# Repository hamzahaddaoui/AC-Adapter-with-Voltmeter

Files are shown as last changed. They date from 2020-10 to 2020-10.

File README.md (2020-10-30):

# AC-Adapter-with-Voltmeter

The project's purpose was to build an AC adapter using linear components (7805 and LM317), since it is made for hobbystic purposes (low currents are drawn). 
One source of voltage is fixed at 5V and the other can be adjusted (1.2v to 14v) using a potentiometer. 

The second part of the project was building a voltmeter, sensing it using the microcontroller internal ADC (16bit) and showing it on the 7-segments display. 
The accuracy of the voltage measurement is about 0.1V.

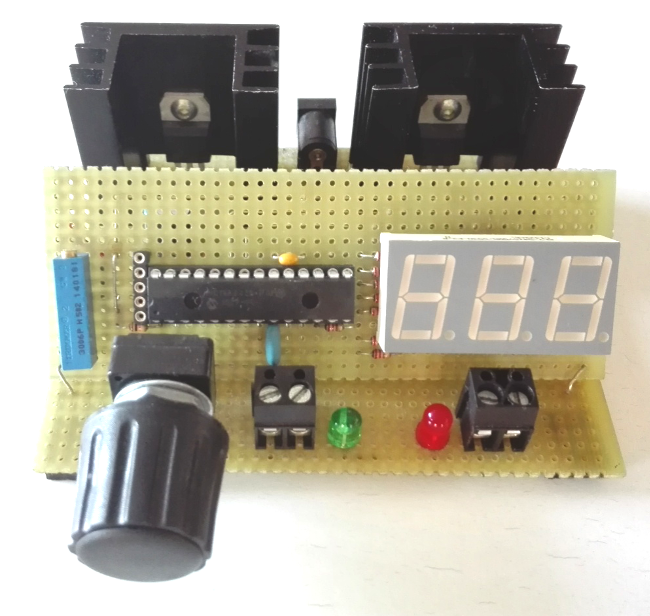
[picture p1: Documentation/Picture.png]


### Electronics schematic

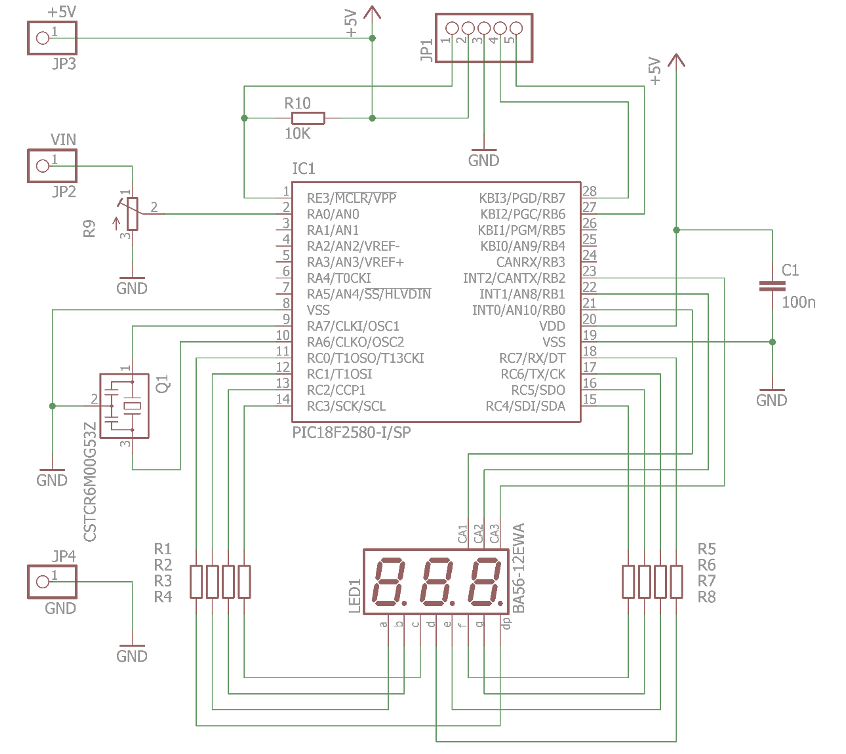
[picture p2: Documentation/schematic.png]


### PCB schematic

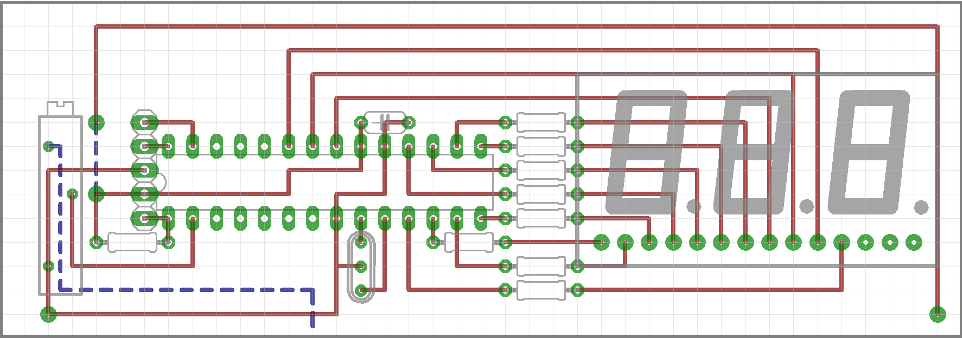
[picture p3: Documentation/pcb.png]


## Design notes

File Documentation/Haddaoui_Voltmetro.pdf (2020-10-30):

# VOLTMETRO A 3 DIGIT

Hamza Haddaoui | 4ECn 2015/16

Il voltmetro è uno strumento (https://it.wikipedia.org/wiki/Strumento_di_misura) per la misura della differenza di potenziale (https://it.wikipedia.org/wiki/Differenza_di_potenziale) elettrico tra due punti di un circuito, (https://it.wikipedia.org/wiki/Circuito_elettrico) la cui unità di misura è il volt (https://it.wikipedia.org/wiki/Volt) con simbolo V.
Come per altri strumenti, i parametri fondamentali di un voltmetro sono:
- la portata
- la sensibilità
Il voltmetro da noi realizzato misura la tensione tra il riferimento (GND) e la tensione variabile in uscita dall'alimentatore.
L'alimentatore fornisce una tensione compresa tra 1,2V e 16V, che viene misurata dal voltmetro con una precisione di 0,1V.
1. Microcontrollore Microchip PIC18F2420
2. Zoccolo a 5 poli per la programmazione
3. Trimmer multigiro 10K
4. Display a 3 cifre (catodo comune)

2

3

4

1

## Funzionamento

Il funzionamento del voltmetro può essere descritto in tre fasi, che vengono eseguite a intervalli ben precisi, dettati dal timer interno, che sono:
- Lettura della tensione (Input);
- Elaborazione dei dati raccolti;
- Visualizzazione della tensione sul display (Output).

### Lettura della tensione

Il primo step riguarda l'acquisizione della tensione, effettuata mediante la lettura analogica della tensione dal micro.
Il pin RA0 del PIC, "legge" la tensione sul trimmer, che non è altro che la tensione variabile erogata dall'alimentatore, partizionata.
Si adotta questa tecnica poiché è necessario
regolare la tensione in ingresso al micro, cioè
“rimappare” la tensione tra 1,2V e 16V in una tensione tra 0 e 5v (in modo proporzionale). Nella fase finale di collaudo è quindi necessario tarare il trimmer per regolare la tensione in ingresso al PIC.

### Elaborazione dati

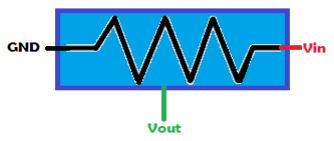
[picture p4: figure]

Successivamente, è necessario elaborare il dato letto sul pin RA0. La conversione A/D utilizzata è a 8bit, cioè ha una risoluzione di circa 60mV.
Una volta letto il byte, bisogna convertirlo in una tensione secondo la proporzione:

byte ∶ tensione = 2

8
∶ 16V

tensione =

byte ∗ 16V

unsigned char var;

var += readADCH0()); | //lettura AN0 e sommatoria

i++;

if (i==40){ | //media su 40 misure

i=0;

tensione=var/40;

var=0;

dividicifre();

}

Un altro appunto molto importante da tenere a mente, è che il regolatore di tensione “LM317” fornisce una tensione in uscita a partire da 1,2V, quindi tensioni più basse sono indice di malfunzionamento del software (oppure, la calibrazione con il trimmer non è stata effettuata correttamente).

La fase successiva consiste nel suddividere la tensione in singole cifre, quali decine, unità e decimi. Fatto ciò, bisogna codificare ogni singola cifra con un codice binario, relativo ai segmenti da accendere:

| a | b | c | d | e | f | g
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
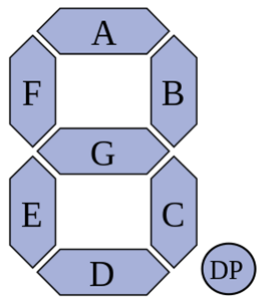
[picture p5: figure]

Ad esempio, per la cifra “7” i segmenti da accendere saranno “a”, “b” e “c”.

### Visualizzazione tensione

Per visualizzare la tensione sul display, è necessario a livello hardware collegare i vari segmenti ai pin relativi del PIC, tramite una resistenza per limitare la corrente sui vari LED.

Nel display utilizzato i segmenti della stessa
lettera sono collegati tra di loro (Il segmento
“a” della prima cifra è collegato con il
segmento “a” della seconda e terza cifra), cosa che risulta molto comoda dal momento che con 7 fili (+ un catodo per ogni cifra) possiamo comandare 3 cifre.
La configurazione del display utilizzato (ELT-541SYGWA) infatti è a catodo comune, cioè

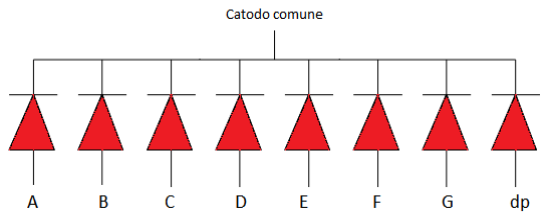
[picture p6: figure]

tutti i segmenti di una cifra, sono collegati da un unico pin sul catodo.

Per visualizzare un numero, basta mandare al display il codice relativo alla prima cifra, attivare il catodo (quindi portarlo a GND), disattivarlo e ripetere la procedura per le altre due cifre.
La velocità con cui viene effettuata questa operazione è così veloce che il nostro occhio non si accorge del continuo accendersi e spegnersi delle cifre.

## Schema elettrico

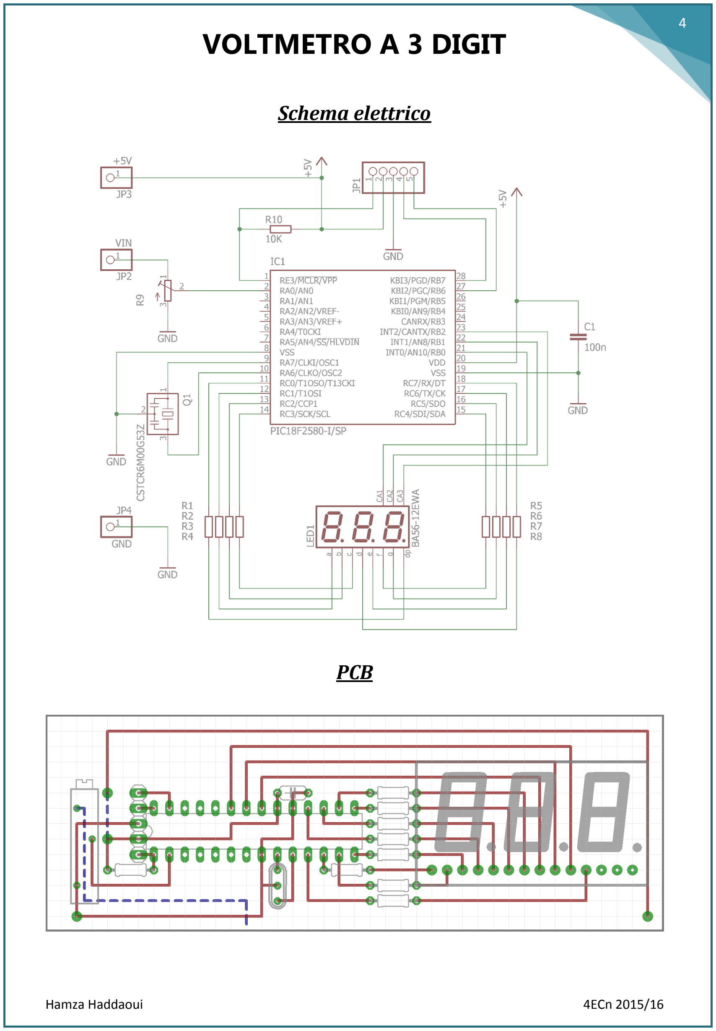
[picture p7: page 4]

## PCB

## Note di montaggio

- Saldare con attenzione lo zoccolo a 28 pin del PIC, facendo in modo che sia perfettamente a contatto con la basetta
- Saldare il connettore da 14 pin per il display, e quello da 5 pin per la programmazione
- Saldare le varie resistenze, il condensatore ed il trimmer
- Il risonatore ceramico non è indispensabile, poiché nel PIC è già integrato un oscillatore

## Collaudo e calibrazione

Il primo collaudo effettuato è stato per verificare che tutti i segmenti del display fossero effettivamente funzionanti.

Successivamente una volta completata la realizzazione della scheda, si passa a un collaudo visivo, tenendo sottomano lo schema PCB del circuito, per individuare varie incongruenze.

La fase successiva riguarda la programmazione del PIC, effettuata con il software MPLAB IDE.
Tramite la strip a 5 poli, si collega il MiniPic al voltmetro, avendo cura di togliere i ponticelli per “scollegare” il PIC18F4580 e programmare appunto il PIC18F2420 presente sul voltmetro.

Se la programmazione va a buon fine, sul display si dovrà visualizzare la scritta “ccc”: a questo punto si passa alla fase di calibrazione.

Nella fase di calibrazione bisogna alimentare il voltmetro (5V, GND) sui relativi pin, e portare il pin Vout su una tensione a piacere (preferibilmente sotto i 5V). A questo punto è necessario regolare il trimmer per leggere sul display la tensione applicata sul pin.

## Problemi riscontrati

Nel realizzare il voltmetro non ho avuto problemi. Dopo aver programmato il microcontrollore, ho notato che i segmenti del display relativi alla “g” non funzionavano. Inizialmente pensavo che fosse un problema del display, invece poi facendo varie prove ho scoperto che era il pin del microcontrollore collegato al pin “g” del display che non funzionava, perciò ho sostituito il microcontrollore.

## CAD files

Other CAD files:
src/output/progetto.obj

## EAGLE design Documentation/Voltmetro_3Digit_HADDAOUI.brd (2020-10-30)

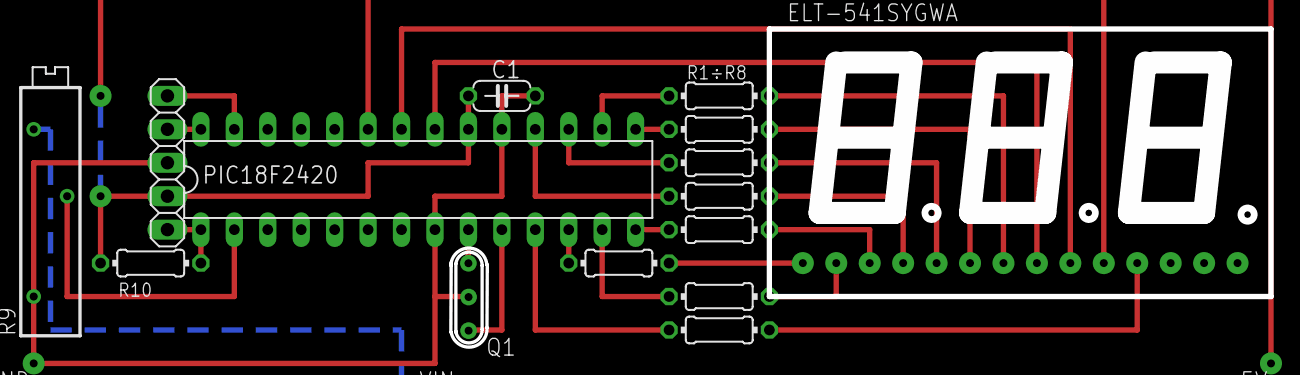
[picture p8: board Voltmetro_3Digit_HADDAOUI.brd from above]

Board: 2 copper layers, 13 parts (0 on the bottom side), 14 nets.

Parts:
C1: 100n; C050-024X044
JP1: 1X05
PIC18F2420: DIL28-3
R1÷R8, R2, R3, R4, R5, R6, R7, R8: 220; 0204/7
R9: 10K; RTRIM3006P
R10: 10K; 0204/7

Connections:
S$2: PIC18F2420.18, R3.1
S$3: PIC18F2420.17, R7.1
S$4: PIC18F2420.15, R2.1
S$5: PIC18F2420.16, R1÷R8.1
S$15: C1.1, R10.1
S$16: C1.2, JP1.3, PIC18F2420.19, R9.1
S$19: PIC18F2420.11, R8.1
S$22: PIC18F2420.12, R5.1
S$23: PIC18F2420.13, R6.1
S$24: PIC18F2420.14, R4.1
S$30: JP1.4, PIC18F2420.28
S$31: JP1.5, PIC18F2420.27
S$33: JP1.1, PIC18F2420.1, R10.2
S$34: PIC18F2420.2, R9.2

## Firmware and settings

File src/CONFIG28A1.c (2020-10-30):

/*
#asm // like this...
movlb (_var) > > 8
rlcf (_var)&0ffh,f
#endasm
asm(“movlb (_var)> >8”);
asm(“rlcf (_var)&0ffh,f”);
void setCN1{	



void setCN1(unsigned char xx){
	extern unsigned char xy;
	xy=xx;
	#asm
		movff	_xy,WREG
		clrf	WREG
		clrf	INTCON
		clrf	_forx
		clrf	_xy
	#endasm
}
*/








// Modulo di configurazione per PIC18F2580
//=============================================================

#pragma	config IESO=OFF, FCMEN=OFF
	
//OSCINT (FREQ <4MHZ,8MHZ,16MHZ,32MHZ>)
//OSCINT_CKOUT	(il segnale di CLOCK è presente sul pin P10)
//OSCXT
//OSCHS
//OSCHSPLL


//defaul OSCINT, FREQ=4MHz RA6/RA7 digital 
#if defined OSCXT
	#pragma config OSC=XT
#elif defined OSCHS
	#pragma config OSC=HS
#elif defined OSCHSPLL
	#pragma config OSC=HSPLL
#elif defined OSCINT
	#pragma config OSC=IRCIO67
#elif defined OSCINTCKOUT
	#pragma config OSC=IRCIO7
#else
	#pragma config OSC=IRCIO67
#endif


#pragma	config BOREN=OFF, PWRT=ON
#pragma config WDT=OFF
#pragma config PBADEN=OFF
#pragma config DEBUG=ON, STVREN=ON, XINST=OFF, LVP=OFF

//=============================================================
//	dichiarazioni di utilità


unsigned char utilechar0,utilechar1,utilechar2,utilechar3;
unsigned int utileint0,utileint1,utileint2,utileint3;
unsigned char kh,kl,hh,hl;

#ifdef MPWM1
	unsigned char contaMPWM1;
#endif
#ifdef MPWM2
	unsigned char contaMPWM2;
#endif
#ifdef MPWM3
	unsigned char contaMPWM3;
#endif
#ifdef MPWM4
	unsigned char contaMPWM4;
#endif
#if defined MPWM1 || defined MPWM2 || defined MPWM3 || defined MPWM4
	unsigned char periodoMPWM;
#endif

//=============================================================

void configPIC(void)
{
	
	//configurazione di default, periferiche tutte disabilitate
	T0CON=0;				//TIMER0
	T1CON=0;				//TIMER1
	T2CON=0;				//TIMER2
	T3CON=0;				//TIMER3
	CCP1CON=0;				//CCP1 (PWM)
	SSPCON1=0;				//MSSP
	RCSTA=0;				//EUSART
	ADCON1=0x0F;ADCON0=0;	//ingressi tutti digitali
	HLVDCON=0;				//HLV
	CANCON=0b00100000;		//CAN
			
	//-------------------------
	OSCCON=0b01100000;		//default 4MHZ
	PLLEN=0;				//default PLL disable

	//--------------------------
	#if defined OSCINT || defined OSCINTCKOUT
		#if FREQMHZ == 8 
			OSCCON=0b01110000;	//8MHZ
		#elif FREQMHZ == 16
			PLLEN=1;			//4MHZ con PLLx4
		#elif FREQMHZ == 32
			OSCCON=0b01110000;	//8MHZ
			PLLEN=1;			//PLLx4
		#endif
	#endif	

	//------------------------------------------------------
	// registri speciali del micro utilizzati
	RXM0EIDH=0;RXM0EIDL=0;	//VPWM1
	RXM1EIDH=0;RXM1EIDL=0;	//VPWM1
	RXF1EIDH=0;RXF1EIDL=0;	//VPWM1
	RXF5EIDH=0;RXF5EIDL=0;	//VPWM1


	//------------------------------------------------------
	// variabili da inizializzare
	#ifdef MPWM1 
		contaMPWM1=0; 
	#endif
	#ifdef MPWM2 
		contaMPWM2=0; 
	#endif
	#ifdef MPWM3 
		contaMPWM3=0; 
	#endif
	#ifdef MPWM4 
		contaMPWM4=0; 
	#endif				

	//------------------------------------------------------
	//	PORTA (default tutti DIGITAL INPUT)
	
	TRISA=0xFF;
	LATA=0;
	ADCON1=0x0F;
	
	#if defined OSCINTCKOUT || defined OSCINT
		#if defined P9OUT
			TRISA7=0;
			#define P9	LATA7
		#else
			#define P9	RA7
		#endif
	#endif
	
	#if defined OSCINTCKOUT
		TRISA6=0;
		#undef P10
	#endif
	
	#if defined OSCINT
		#if defined P10OUT
			TRISA6=0;
			#define P10	LATA6
		#else
			#define P10	RA6
		#endif
	#endif

	#ifdef P7OUT
		TRISA5=0;
		#define P7	LATA5
	#else
		#define P7 	RA5
	#endif

	#ifndef P6COUNTER0CKI
		#ifdef P6OUT
			TRISA4=0;
			#define P6	LATA4
		#else
			#define P6 	RA4
		#endif
	#endif
	
	#ifdef P5OUT
		TRISA3=0;
		#define P5	LATA3
	#else
		#define P5 	RA3
	#endif
	
	#ifdef P4OUT
		TRISA2=0;
		#define P4	LATA2
	#else
		#define P4 	RA2
	#endif

	#ifdef P3OUT
		TRISA1=0;
		#define P3	LATA1
	#else
		#define P3	RA1
	#endif

	#ifdef P2OUT
		TRISA0=0;
		#define P2	LATA0
	#else
		#define P2	RA0
	#endif
		
	//------------------------portB

	TRISB=0xFF;
	LATB=0;
	
	#ifdef RPULLUP
		RBPU=0;
	#endif
		
	#if !defined intP21
		#ifdef P21OUT
			TRISB0=0;
			#define P21	LATB0
		#else
			#define P21 RB0
		#endif
	#else
		#define P21 RB0		
	#endif
	
	#if !defined intP22
		#ifdef P22OUT
			TRISB1=0;
			#define P22	LATB1
		#else
			#define P22 RB1
		#endif
	#else
		#define P22 RB1		
	#endif
	
	#ifdef P23OUT
		TRISB2=0;
		#define P23	LATB2
	#else
		#define P23 RB2
	#endif

		
	#ifdef P24OUT
		TRISB3=0;
		#define P24	LATB3
	#else
		#define P24 RB3
	#endif
	
	#ifdef P25OUT
		TRISB4=0;
		#define P25	LATB4
	#else
		#define P25 RB4
	#endif
	
	#ifdef P26OUT
		TRISB5=0;
		#define P26	LATB5
	#else
		#define P26 RB5
	#endif

	//-----------------------PORTC
	
	TRISC=0xFF;
	LATC=0;
	CCP1CON=0;
	SSPCON1=0;
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

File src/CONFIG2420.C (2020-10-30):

//configurazione 18F2420
#include <htc.h>

#pragma config OSC = INTIO7, PWRT = ON,BOREN = OFF,WDT = OFF,PBADEN = OFF
#pragma config MCLRE = ON,LVP = OFF,DEBUG = ON
#define interruptTIMER0(void) interrupt TIMER0(void)

#define BYTE1 LATC
#define P21 LATB0
#define P22 LATB1
#define P23 LATB2
unsigned int usec;
unsigned int restart;

void configPIC (void){
	LATC=0;
	TRISC=0;
	LATB=0;
	TRISB=0b11111000;
	OSCCON=0b01100000;	//4MHz
	ADCON0=1;
	ADCON1=0b00001110;
	ADCON2=0b00100100;
	//T0CON=0b01000100;	//:32 (cost. 62)
	TMR0=62;
	INTCON=0;
}

unsigned char readADCH0(void){
	unsigned char datoAD;

	ADCON0=0b00000011;
	while (GODONE)continue;
	ADIF=0;
	datoAD=ADRESH;
	return datoAD;
}

void restartTIMER0(void){

	TMR0=-(restart/32);
	TMR0IF=0;
}

void setTIMER0CKINT(usec){
	restart=usec;
	T0CON=0b01000100;	//:32
	TMR0IF=0;
	TMR0=usec/32;
}


void setAD(char nbit, char nch){
	ADCON0=0b00000001;			//AD on
	//if(nbit==8)ADCON2=0b00000010; 
	//else ADCON2=0b10000010;
	if(nbit==8)ADCON2=0b00100010; 
	else ADCON2=0b10100010;
		
	switch (nch){
		case 1:	ADCON1=0b00001110;break;
		case 2: ADCON1=0b00001101;break;
		case 3: ADCON1=0b00001100;break;
		case 4: ADCON1=0b00001011;break;
	}
}
	
void enintGLOB(){
	GIE=1;
}			 //abilitazione interrupt globale

void enintTIMER0(){
	TMR0IE=1;
	TMR0ON=1;
}			 //abilitazione interrupt TIMER0

void onTIMER0(){
	TMR0ON=1;
}				 //abilitazione TIMER0
